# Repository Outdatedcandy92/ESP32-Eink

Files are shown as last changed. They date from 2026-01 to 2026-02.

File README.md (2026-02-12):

# ESP32 E-INK Board

A tiny E-Ink display driver board featuring an ESP32-C3 and an onboard battery charging IC. It wirelessly drives a 2.13-inch E-Ink display and is designed for portable, ultra-low-power projects such as status displays, or dashboards.



---
## Schematic



---
## PCB



---
## BOM

| Name | Description | Quantity | Price | Shipping |
| --- | --- | --- | --- | --- |
| PCB & Stencil | PCB & Stencil from JLCPCB | - | $10.10 | $8.47 |
| Componenets | Components from LCSC. Detailed breakdown [here](./production/bom.csv) | - | $25.72 | $13.75 |
| [E-Ink Display](https://www.alibaba.com/product-detail/E-paper-Technology-2-13-Inch_1601018719280.html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) | E-Ink Display from Alibaba | 1 | $6.76 | $9.66 |
| Sub Total | | | **$42.58** | **$31.88** |
| Total | | | **$74.46** | |

---

## License

This project is licensed under the CERN Open Hardware Licence Version 2 Weakly Reciprocal [(CERN OHL W)](LICENSE.txt)

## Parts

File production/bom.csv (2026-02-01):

Reference | Qty | Footprint | Value | LCSC Part
AE1 | 1 | RF_Antenna:Johanson_2450AT18x100 | Antenna | C89334
C1,C3,C5,C16,C29 | 5 | Capacitor_SMD:C_0402_1005Metric | 100nF | C1525
C2,C7,C8,C9,C20,C21,C22,C23,C24,C25,C26,C27,C28,C30,C34 | 15 | Capacitor_SMD:C_0402_1005Metric | 1uF | C52923
C4,C17,C18,C19,C33,C35 | 6 | Capacitor_SMD:C_0402_1005Metric | 10uF | C315248
C6 | 1 | Capacitor_SMD:C_0402_1005Metric | 10nF | C15195
C10,C11 | 2 | Capacitor_SMD:C_0402_1005Metric | 17pF | C1517782
C12,C13 | 2 | Capacitor_SMD:C_0402_1005Metric | 10pF | C76946
C14,C15 | 2 | Capacitor_SMD:C_0201_0603Metric | 1.2pF | C85895
C31,C32 | 2 | Capacitor_SMD:C_0402_1005Metric | 4.7uF | C6119795
D1,D2,D3 | 3 | Diode_SMD:D_SOD-123 | MBR0530 | C82046
D4,D5 | 2 | LED_SMD:LED_0402_1005Metric | LED | C30584803
H1,H2 | 2 | MountingHole:MountingHole_2.2mm_M2 | MountingHole | -
J1 | 1 | easyeda2kicad:FPC-SMD_24P-P0.50_05B20U24P | Conn_01x26 | C5362165
J2 | 1 | Connector_JST:JST_SH_BM02B-SRSS-TB_1x02-1MP_P1.00mm_Vertical | BAT | C160402
L1 | 1 | Inductor_SMD:L_0402_1005Metric | 2.0nH | C2986275
L2 | 1 | Inductor_SMD:L_0402_1005Metric | 24nH | C167472
L3 | 1 | Inductor_SMD:L_0201_0603Metric | 2.4nH | C2043647
L4 | 1 | Inductor_SMD:L_1008_2520Metric | 2.2uH | C1333325
L5 | 1 | easyeda2kicad:IND-SMD_L4.0-W4.0_FNR40XXS | 10uH | C167879
Q1 | 1 | Package_TO_SOT_SMD:SOT-323_SC-70 | Si1304BDL | C7419947
R1,R3,R9,R10 | 4 | Resistor_SMD:R_0402_1005Metric | 10K | C25531
R2 | 1 | Resistor_SMD:R_0402_1005Metric | 499 | C4125
R4,R5 | 2 | Resistor_SMD:R_0402_1005Metric | 22 | C25092
R6,R7 | 2 | Resistor_SMD:R_0402_1005Metric | 5.1k | C25905
R8 | 1 | Resistor_SMD:R_0402_1005Metric | 100 | C25076
R11 | 1 | Resistor_SMD:R_0402_1005Metric | 0.47 | C2771738
R12,R13 | 2 | Resistor_SMD:R_0402_1005Metric | 1.5K | C25867
R14 | 1 | Resistor_SMD:R_0402_1005Metric | 1.78K | C113478
R15 | 1 | Resistor_SMD:R_0402_1005Metric | 3.24K | C11457
SW1,SW2 | 2 | easyeda2kicad:SW-SMD_L3.9-W3.0-P4.45 | SW_Push | C720477
TP1,TP2,TP3,TP4,TP5,TP6,TP7,TP8 | 8 | TestPoint:TestPoint_Keystone_5000-5004_Miniature | TestPoint | C5199802
U1 | 1 | Package_DFN_QFN:QFN-32-1EP_5x5mm_P0.5mm_EP3.7x3.7mm | ESP32-C3 | C2858491
U2 | 1 | Package_SON:Texas_DRC0010J_ThermalVias | TPS63001 | C28060
U3 | 1 | Package_TO_SOT_SMD:SOT-23-6 | USBLC6-2SC6 | C7519
U5 | 1 | Package_DFN_QFN:VQFN-16-1EP_3x3mm_P0.5mm_EP1.6x1.6mm | BQ24074RGT | C54313
USB1 | 1 | easyeda2kicad:USB-C-SMD_TYPE-C-6PIN-2MD-073 | TYPE-C 16PIN 2MD(073) | C2765186
Y1 | 1 | Crystal:Crystal_SMD_2016-4Pin_2.0x1.6mm | 40Mhz | C255898
Y2 | 1 | Crystal:Crystal_SMD_2012-2Pin_2.0x1.2mm | 32.768 kHz | C99009

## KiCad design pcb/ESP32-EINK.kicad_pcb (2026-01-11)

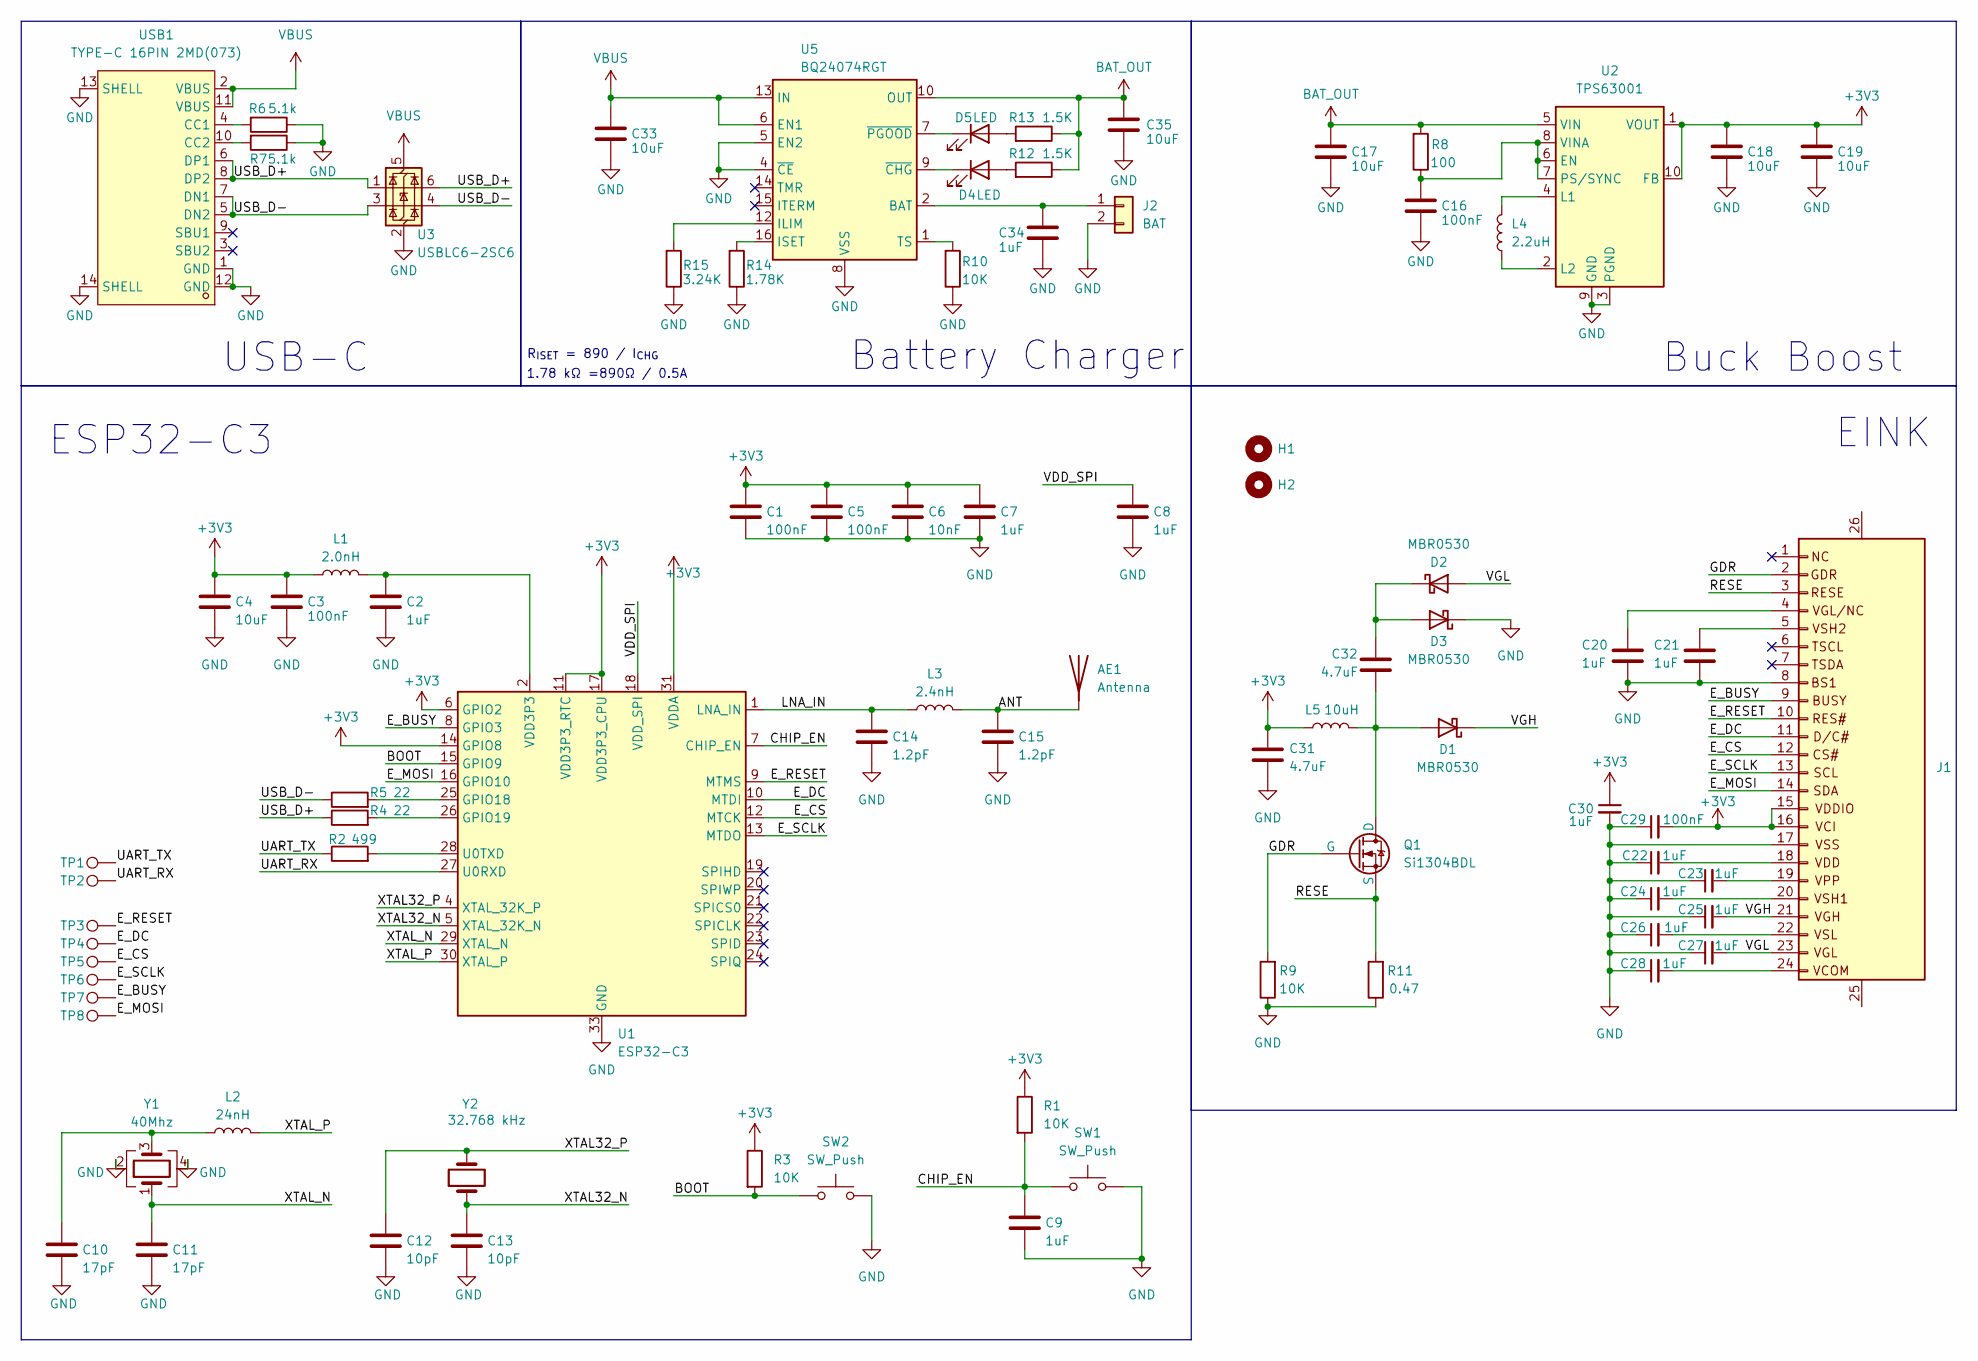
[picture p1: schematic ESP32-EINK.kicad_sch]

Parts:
AE1: Antenna; Johanson_2450AT18x100; LCSC Part C89334
C1, C3, C5, C16, C29: 100nF; C_0402_1005Metric; LCSC Part C1525
C2, C7, C8, C9, C20, C21, C22, C23, C24, C25, C26, C27, C28, C30, C34: 1uF; C_0402_1005Metric; LCSC Part C52923
C4, C17, C18, C19, C33, C35: 10uF; C_0402_1005Metric; LCSC Part C315248
C6: 10nF; C_0402_1005Metric; LCSC Part C15195
C10, C11: 17pF; C_0402_1005Metric; LCSC Part C1517782
C12, C13: 10pF; C_0402_1005Metric; LCSC Part C76946
C14, C15: 1.2pF; C_0201_0603Metric; LCSC Part C85895
C31, C32: 4.7uF; C_0402_1005Metric; LCSC Part C23733
D1, D2, D3: MBR0530; D_SOD-123; LCSC Part C82046
D4, D5: LED; LED_0402_1005Metric; LCSC Part C30584803
H1, H2: MountingHole; MountingHole_2.2mm_M2
J1: Conn_01x26; FPC-SMD_24P-P0.50_05B20U24P; LCSC Part C5362165
J2: BAT; JST_SH_BM02B-SRSS-TB_1x02-1MP_P1.00mm_Vertical; LCSC Part C160402
L1: 2.0nH; L_0402_1005Metric; LCSC Part C2986275
L2: 24nH; L_0402_1005Metric; LCSC Part C167472
L3: 2.4nH; L_0201_0603Metric; LCSC Part C2043647
L4: 2.2uH; L_1008_2520Metric; LCSC Part C1333325
L5: 10uH; IND-SMD_L4.0-W4.0_FNR40XXS; LCSC Part C167879
Q1: Si1304BDL; SOT-323_SC-70; LCSC Part C7419947
R1, R3, R9, R10: 10K; R_0402_1005Metric; LCSC Part C25531
R2: 499; R_0402_1005Metric; LCSC Part C4125
R4, R5: 22; R_0402_1005Metric; LCSC Part C25092
R6, R7: 5.1k; R_0402_1005Metric; LCSC Part C25905
R8: 100; R_0402_1005Metric; LCSC Part C25076
R11: 0.47; R_0402_1005Metric; LCSC Part C2771738
R12, R13: 1.5K; R_0402_1005Metric; LCSC Part C25867
R14: 1.78K; R_0402_1005Metric; LCSC Part C113478
R15: 3.24K; R_0402_1005Metric; LCSC Part C11457
SW1, SW2: SW_Push; SW-SMD_L3.9-W3.0-P4.45; LCSC Part C720477
TP1, TP2, TP3, TP4, TP5, TP6, TP7, TP8: TestPoint; TestPoint_Keystone_5000-5004_Miniature; LCSC Part C5199802
U1: ESP32-C3; QFN-32-1EP_5x5mm_P0.5mm_EP3.7x3.7mm; LCSC Part C2858491
U2: TPS63001; Texas_DRC0010J_ThermalVias; LCSC Part C28060
U3: USBLC6-2SC6; SOT-23-6; LCSC Part C7519
U5: BQ24074RGT; VQFN-16-1EP_3x3mm_P0.5mm_EP1.6x1.6mm; LCSC Part C54313
USB1: TYPE-C 16PIN 2MD(073); USB-C-SMD_TYPE-C-6PIN-2MD-073; LCSC Part C2765186
Y1: 40Mhz; Crystal_SMD_2016-4Pin_2.0x1.6mm; LCSC Part C255898
Y2: 32.768 kHz; Crystal_SMD_2012-2Pin_2.0x1.2mm; LCSC Part C99009

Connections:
+3V3: C1.1, C3.1, C4.1, C5.1, C6.1, C7.1, C18.1, C19.1, C29.2, C30.1, C31.1, J1.15, J1.16, L1.1, L5.1, R1.1, R3.1, U1.6 (GPIO2), U1.11 (VDD3P3_RTC), U1.14 (GPIO8), U1.17 (VDD3P3_CPU), U1.31 (VDDA), U1.32 (VDDA), U2.1 (VOUT), U2.10 (FB)
/ANT: AE1.1 (A), C15.1, L3.2
/BOOT: R3.2, SW2.1, U1.15 (GPIO9)
/CHIP_EN: C9.1, R1.2, SW1.1, U1.7 (CHIP_EN)
/E_BUSY: J1.9, TP7.1, U1.8 (GPIO3)
/E_CS: J1.12, TP5.1, U1.12 (MTCK)
/E_DC: J1.11, TP4.1, U1.10 (MTDI)
/E_MOSI: J1.14, TP8.1, U1.16 (GPIO10)
/E_RESET: J1.10, TP3.1, U1.9 (MTMS)
/E_SCLK: J1.13, TP6.1, U1.13 (MTDO)
/GDR: J1.2, Q1.2 (G), R9.2
/LNA_IN: C14.1, L3.1, U1.1 (LNA_IN)
/RESE: J1.3, Q1.3 (S), R11.2
/UART_RX: TP2.1, U1.27 (U0RXD)
/UART_TX: R2.1, TP1.1
/USB_D+: R4.1, U3.1 (I/O1), U3.6 (I/O1), USB1.6 (DP1), USB1.8 (DP2)
/USB_D-: R5.1, U3.3 (I/O2), U3.4 (I/O2), USB1.5 (DN2), USB1.7 (DN1)
/VDD_SPI: C8.1, U1.18 (VDD_SPI)
/VGH: C25.2, D1.1 (K), J1.21
/VGL: C27.2, D2.2 (A), J1.23
/XTAL32_N: C13.1, U1.5 (XTAL_32K_N), Y2.1
/XTAL32_P: C12.1, U1.4 (XTAL_32K_P), Y2.2
/XTAL_N: C11.1, U1.29 (XTAL_N), Y1.1
/XTAL_P: L2.2, U1.30 (XTAL_P)
BAT_OUT: C17.1, C35.1, R8.2, R12.1, R13.1, U2.5 (VIN), U5.10 (OUT), U5.11 (OUT)
GND: C1.2, C2.2, C3.2, C4.2, C5.2, C6.2, C7.2, C8.2, C9.2, C10.2, C11.2, C12.2, C13.2, C14.2, C15.2, C16.2, C17.2, C18.2, C19.2, C20.1, C21.1, C22.1, C23.1, C24.1, C25.1, C26.1, C27.1, C28.1, C29.1, C30.2, C31.2, C33.2, C34.2, C35.2, D3.1 (K), J1.8, J1.17, J2.2, R6.1, R7.1, R9.1, R10.1, R11.1, R14.1, R15.1, SW1.2, SW2.2, U1.33 (GND), U2.3 (PGND), U2.9 (GND), U2.11 (PGND), U3.2 (GND), U5.4 (~CE), U5.5 (EN2), U5.8 (VSS), U5.17 (VSS), USB1.1 (GND), USB1.12 (GND), USB1.13 (SHELL), USB1.14 (SHELL), Y1.2, Y1.4
unnamed: C2.1, L1.2, U1.2 (VDD3P3), U1.3 (VDD3P3)
unnamed: C10.1, L2.1, Y1.3
unnamed: C32.2, D1.2 (A), L5.2, Q1.1 (D)
unnamed: C32.1, D2.1 (K), D3.2 (A)
unnamed: D4.2 (A), R12.2
unnamed: D4.1 (K), U5.9 (~CHG)
unnamed: D5.2 (A), R13.2
unnamed: D5.1 (K), U5.7 (~PGOOD)
unnamed: C20.2, J1.4
unnamed: C21.2, J1.5
unnamed: C22.2, J1.18
unnamed: C23.2, J1.19
unnamed: C24.2, J1.20
unnamed: C26.2, J1.22
unnamed: C28.2, J1.24
unnamed: C34.1, J2.1, U5.2 (BAT), U5.3 (BAT)
unnamed: R5.2, U1.25 (GPIO18)
unnamed: R4.2, U1.26 (GPIO19)
unnamed: R2.2, U1.28 (U0TXD)
unnamed: C16.1, R8.1, U2.6 (EN), U2.7 (PS/SYNC), U2.8 (VINA)
unnamed: L4.2, U2.4 (L1)
unnamed: L4.1, U2.2 (L2)
unnamed: R15.2, U5.12 (ILIM)
unnamed: R14.2, U5.16 (ISET)
unnamed: R10.2, U5.1 (TS)
unnamed: R6.2, USB1.4 (CC1)
unnamed: R7.2, USB1.10 (CC2)
VBUS: C33.1, U3.5 (VBUS), U5.6 (EN1), U5.13 (IN), USB1.2 (VBUS), USB1.11 (VBUS)

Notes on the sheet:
ESP32-C3
Buck Boost
Battery Charger
1.78 kΩ =890Ω / 0.5A
R_{ISET} = 890 / I_{CHG}
USB-C
EINK

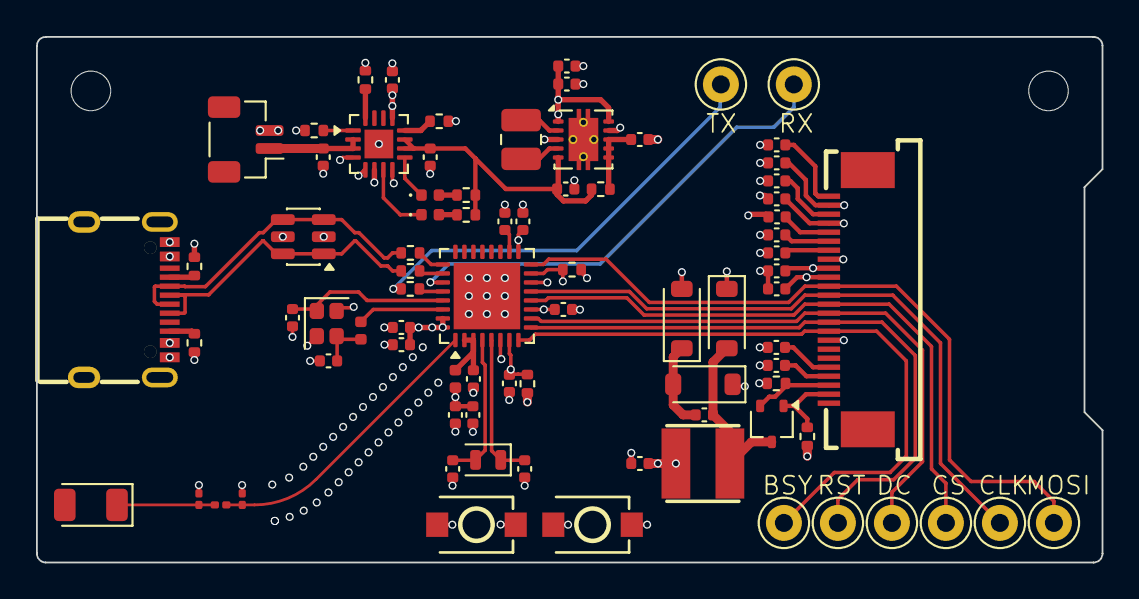
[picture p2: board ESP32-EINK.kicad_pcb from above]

Board: 4 copper layers, 59.2 x 29.2 mm, 83 parts (0 on the bottom side), 54 nets.

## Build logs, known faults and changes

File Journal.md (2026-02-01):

## 29/12/25

Saw this really [cool thing](https://www.reddit.com/r/esp32/comments/1kgrwxk/minimal_github_commit_tracker_using_an_esp32_and/) on reddit a while ago and I knew right at that moment that I had to make one for myself.



It's basically just an E-Ink display with an ESP32 on the back; seems pretty simple to make at first glance;  and so I started my journey.

I started off by just searching what main MCU I want to use and eventually ended up selecting the ESP32-C3 as it can be programmed over USB, has 4mb of internal flash, and is very power efficient. It had everything I needed!

Moving on to designing the actual schematics now. Espressif provides nice [hardware design guidelines](https://docs.espressif.com/projects/esp-hardware-design-guidelines/en/latest/esp32c3/index.html) for the C3 chips so that's what I've referred to for this project.



This was my minimal schematic for the ESP32-C3 It's got some power filtering for the VDD3P3, and got an RF matching circuitry in which for now I've just used the recommended values for the matching circuitry provided in the guide (I will most likely change this later).

Now after setting up the minimal schematics I though I was actually cooked because I needed 4 free GPIO pins for SPI and I initially thought I could not use the JTAG pins as GPIO, so yeah I uh basically just gave up for 5 minutes and then realized that these pins can have an alternate function of GPIO so I was safe; I could actually assign SPI on those pins and drive the E-Ink display.

Oh and I also decided to add an external clock source for the RTC clock to decrease average power consumption. I figured that since I'm going to be putting the ESP32 in deep sleep most of the time, having an external crystal would be helpful.

For my power I decided to use a buck boost convertor because I'm actually planning to power this from a battery and would like for it be as efficient as it possibly can. I used the TPS63001 as the chosen convertor as it's high efficiency and tiny.



### Time Spent: 2.5 Hours

--- 

## 30/12/25

I added circuitry for driving an E-ink display today. For this I mainly referred to a few different websites; some of which are [adafruit](https://cdn-learn.adafruit.com/assets/assets/000/127/535/original/eink___epaper_schem.png?1707320728), [waveshare](https://www.waveshare.com/w/upload/5/57/2.13inch_e-Paper_HAT_Schematic.pdf),[alibaba page](https://www.alibaba.com/product-detail/E-paper-Technology-2-13-Inch_1601018719280.html) (for pinout and information about drivers).

In the end I ended up with the circuitry down below; looks pretty complex but all it really does is take 3.3v In and boosts it using the mosfet circuitry you see on the left side to power itself up.



*final schematic*



Moving on I assigned everything temporary footprints (I hate assigning footprints), went with 0402s components and moved onto the actual PCB design.



I started off with assigning some net classes and color coding them to get a better visual 



I then drew a rectangle using the dimensions of the E-Ink display just to get a sense of scale and see how I should place everything. (I didn't make a board edge layer yet)



Started off with laying out the E-Ink circuitry as it was pretty easy

![image](https://hc-cdn.hel1.your-objectstorage.com/s/v3/1ece0b861686e43e_O_nE4to6JmwNSfpAPRXueuDkuWGYionTHYIaIiIgkjWUmIiIikjQGM0RERCRpDGaIiIhI0hjMEBERkaQxmCEiIiJJYzBDREREksZ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)

And then moved onto the ESP32 which was way harder



The ESP32 pinout is questionable I would say. The 40Mhz crystal is like pretty close to the LNA pin and fitting the decoupling capacitors close is really hard when they are in 0402 package; which is why I'm considering switching to 0201s. But that's a job for tomorrow as I was pretty tired at this point.

Here's how my final PCB look at the end of today



### Time Spent: 3 Hours

---
## 10/01/26 and 11/01/26

FYI this journal entry is for what I've done yesterday and today.

I first started off by adding a LiPo charger IC on board, I did some research and ended up using the **BQ24074R**. To be honest I spent way to much time reading the datasheet to figure out how to configure this thing properly.

I wanted to set the current input limit to 500mA because I plan on powering it from USB 2.0 sources, so I connected my EN pins appropriately to set USB500 mode.



Other configurations were easy and pretty straightforward, I used the formula given by TI to set the fast charge current to 0.5A or 500mA.



But the ILIM pin is was confused me a lot, because in the datasheet it said to never leave it floating, where as since I'm in USB500 mode it shouldn't matter and that's what a design reference said.





So I spent a good 30 minutes trying to figure this out but in the end I gave up and just connected a resistor going to ground from ILIM anyways, I figured let's just be safe rather than sorry later.



After finishing up my schematics I moved onto the PCB layout.





Now routing was relatively straightforward for this board. The only place where I needed to put some effort was the LNA line, where I had to impedance match it to 50 Ohms. For this I referred to JLCPCB's Impedance calculator and found what trace width I would need with a specific board stackup.

I went with **JLC04161H-3313** stackup as it doesn't require any extra charge and It has a reasonable trace width for a 50 Ohms microstrip.



I set up my a net class for the antenna traces to follow the required width and while routing out the antenna lines I decided to make use of the kicad RF-Tools plugin. I used it to round my tracks and also add fencing vias.
I had to do a bit of math to get the offset for fencing vias. To get the distance between the vias, I used the formula:

distance between vias = wavelength/8

I used Saturn PCB toolkit to calculate the wavelength based on the frequency and dielectric constant.



I set my via fence according to the calculations 



Here's how the rest of my board looked when I finished routing



I decided to not use these square test pads and instead add footprint for Keystone's test points, which are cool little things which can basically plug into the hole and then you can attach a test probe onto them. No soldering or anything is required.




The PCB was finished at this point, all I needed to do was assign component values. And so I spent like the next 30 minutes copy pasting LCSC part numbers into KiCad.



I also made a few changes such as switching to a smaller footprint crystals, and getting a better inductor with minimal DCR. This caused a few footprints to change, so I quickly had to reroute a few things.



This was pretty much it for this project, after finishing the PCB I spent some time on LCSC making a cart and then setting up the repository for this project.

## Time Spent:  7.5 Hours

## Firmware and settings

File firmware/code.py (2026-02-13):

# SPDX-FileCopyrightText: 2017 Scott Shawcroft, written for Adafruit Industries
# SPDX-FileCopyrightText: Copyright (c) 2021 Waveshare team, 2023 Mikko Pitkänen
#
# SPDX-License-Identifier: MIT
"""
`epd_2in13_b`
================================================================================

FIRMWARE HAS NOT YET BEEN TESTED ON THE BOARD

Circuitpython library to use Waveshare 2.13 inch ePaper display with a ESP32-C3

* Author(s): Waveshare team, Mikko Pitkänen
* Adapted for ESP32 by: Outdatedcandy92

Implementation Notes
--------------------

This is a Circuitpython version of Waveshare 2.13" epaper display lib adapted for ESP32-C3 
based on Waveshare team's micropython class and Mikko Pitkänen's Pico W implementation.

Key differences from Pico version:
* Pin definitions changed for ESP32 GPIO
* SPI configuration adjusted for ESP32 hardware

**Hardware:**

* `Waveshare 2.13inch E-Paper E-Ink Display Module (B) for Raspberry Pi Pico https://www.waveshare.com/pico-epaper-2.13-b.htm`_
* `Waveshare 2.13inch E-Paper wiki https://www.waveshare.com/wiki/Pico-ePaper-2.13-B`_
* `Display module specification sheet https://www.waveshare.com/w/upload/d/d8/2.13inch_e-Paper_%28B%29_V3_Specification.pdf`_
* `Waveshare ePaper github pages https://github.com/waveshare/Pico_ePaper_Code`_


**Software and Dependencies:**

* Adafruit CircuitPython firmware for ESP32-C3:
  https://circuitpython.org/downloads




"""

# imports

__version__ = "0.0.1+auto.0"
__repo__ = "https://github.com/tomduud/CircuitPython_EPD_2in13_B.git"

import time

import digitalio
import busio
import adafruit_framebuf
import board


#define constant pins for ESP32-C3 
RST_PIN         = board.GP4
DC_PIN          = board.GP5 
CS_PIN          = board.GP6
BUSY_PIN        = board.GP3 

EPD_WIDTH       = 104
EPD_HEIGHT      = 212

class EPD_2in13_B:
    def __init__(self, rotation):
        # create the spi device and pins we will need
        self.spi = busio.SPI(clock=board.GP7, MOSI=board.GP10)

        self.cs = digitalio.DigitalInOut(CS_PIN)
        self.cs.direction = digitalio.Direction.OUTPUT
        self.dc = digitalio.DigitalInOut(DC_PIN)
        self.dc.direction = digitalio.Direction.OUTPUT
        self.rst = digitalio.DigitalInOut(RST_PIN)
        self.rst.direction = digitalio.Direction.OUTPUT
        self.busy = digitalio.DigitalInOut(BUSY_PIN)
        self.width = EPD_WIDTH
        self.height = EPD_HEIGHT

        self.framebuffer_black_array = bytearray(self.height * self.width // 8)
        self.framebuffer_red_array = bytearray(self.height * self.width // 8)
        self.framebuffer_black = adafruit_framebuf.FrameBuffer(self.framebuffer_black_array, self.width, self.height, adafruit_framebuf.MHMSB)
        self.framebuffer_red = adafruit_framebuf.FrameBuffer(self.framebuffer_red_array, self.width, self.height, adafruit_framebuf.MHMSB)

        self.framebuffer_black.rotation=rotation
        self.framebuffer_red.rotation=rotation

        self.init()

    def init(self):
        self.reset()
        self.send_command(0x04)
        self.ReadBusy()  # waiting for the electronic paper IC to release the idle signal

        self.send_command(0x00)  # panel setting
        self.send_data(0x0f)  # LUT from OTP,128x296
        self.send_data(0x89)  # Temperature sensor, boost and other related timing settings

        self.send_command(0x61)  # resolution setting
        self.send_data(0x68) # resolution setting
        self.send_data(0x00) # resolution setting
        self.send_data(0xD4) # resolution setting

        self.send_command(0x50)  # VCOM AND DATA INTERVAL SETTING
        self.send_data(0x87) # data Inteval

        print('Display initialized')

        return 0

    # Hardware reset
    def reset(self):
        self.digital_write(self.rst, True)
        self.delay_ms(50)
        self.digital_write(self.rst, False)
        self.delay_ms(2)
        self.digital_write(self.rst, True)
        self.delay_ms(50)

    def send_command(self, command):
        self.digital_write(self.dc, False)
        self.digital_write(self.cs, False)
        self.spi_writebyte([command])
        self.digital_write(self.cs, True)

    def digital_write(self, pin, value):
        pin.value = value

    def digital_read(self, pin):
        return pin.value

    def delay_ms(self, delaytime):
        time.sleep(delaytime / 1000.0)

    def spi_writebyte(self, data):
        while not self.spi.try_lock():
            pass
        try:
            self.spi.configure(baudrate=40000000, phase=0, polarity=0)
            self.cs.value = False
            self.spi.write(bytearray(data))
            self.cs.value = True
        finally:
            self.spi.unlock()

    def ReadBusy(self):
        print('Display busy')
        self.send_command(0x71)
        while (self.digital_read(self.busy) == 0):
            self.send_command(0x71)
            self.delay_ms(10)
        print('Display free')

    def send_data(self, data):
        self.digital_write(self.dc, True )
        self.digital_write(self.cs, False)
        self.spi_writebyte([data])
        self.digital_write(self.cs, True)

    def Clear(self, colorblack, colorred):
        self.send_command(0x10)
        for j in range(0, self.height):
            for i in range(0, int(self.width / 8)):
                self.send_data(colorblack)
        self.send_command(0x13)
        for j in range(0, self.height):
            for i in range(0, int(self.width / 8)):
                self.send_data(colorred)

        self.TurnOnDisplay()

    def TurnOnDisplay(self):
        self.send_command(0x12)
        self.ReadBusy()

    def sleep(self):
        self.send_command(0X50)
        self.send_data(0xf7)
        self.send_command(0X02)
        self.ReadBusy()
        self.send_command(0x07)  # DEEP_SLEEP
        self.send_data(0xA5)  #TODO check this code
        self.delay_ms(2000)

    def display(self):
        self.send_command(0x10)
        for j in range(0, self.height):
            for i in range(0, int(self.width / 8)):
                self.send_data(self.framebuffer_black_array[i + j * int(self.width / 8)])
        self.send_command(0x13)
        for j in range(0, self.height):
            for i in range(0, int(self.width / 8)):
                self.send_data(self.framebuffer_red_array[i + j * int(self.width / 8)])
        self.TurnOnDisplay()

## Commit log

2026-01-11 rev 1
    [ESP32-EINK.kicad_pcb, ESP32-EINK.kicad_sch, bom.csv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]
2026-01-24 Update component reference for C31,C32 in bom.csv
    [bom.csv]
2026-02-01 bom update
